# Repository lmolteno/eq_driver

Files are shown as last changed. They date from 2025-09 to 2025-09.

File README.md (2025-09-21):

# EQ Driver
## EQ3
Gear ratios:
RA seems to be about 5.46875:1 from the stepper to the worm, then the worm is about 130:1 (according to what I've read).

RA Stepper:
Big Gear: 66 teeth
interfaces with Stepper motor: 12 teeth

Big gear is attached to 35 teeth gear.
This is attached to another 35 tooth gear.
Total ratio is 66:12

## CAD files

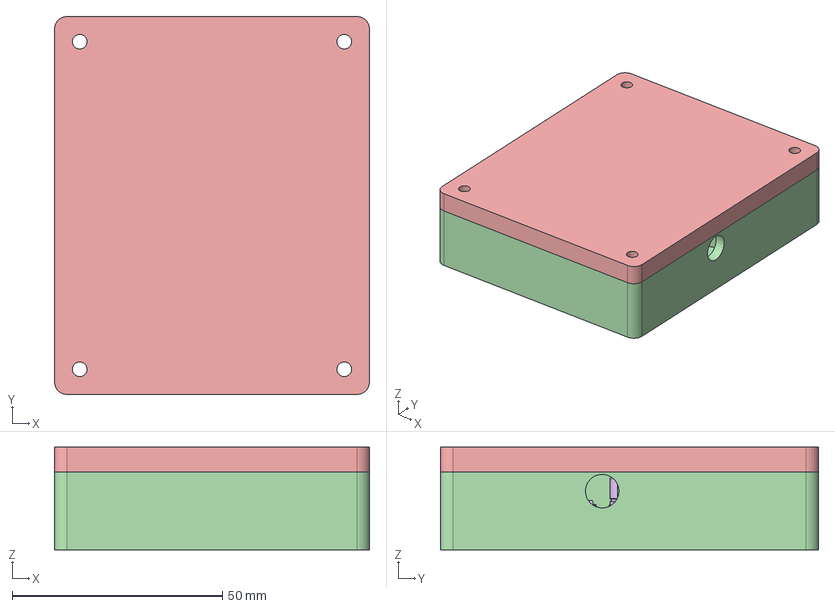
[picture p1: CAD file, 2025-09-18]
eq3_driver.FCStd
75.0 x 90.0 x 24.5 mm
Pcb_4df3
C34_C_0402_1005Metric_825b499ae89d x 18
R11_R_1206_3216Metric_94f444638870 x 4
SW-SMD_L3.9-W2.9-H2.0-LS4.8 x 3
SW-SMD_L3.9-W2.9-H2.0-LS4.009 x 3
SW-SMD_L3.9-W2.9-H2.0-LS4.010 x 3
SW-SMD_L3.9-W2.9-H2.0-LS4.011 x 3
SW-SMD_L3.9-W2.9-H2.0-LS4.012 x 3
SW-SMD_L3.9-W2.9-H2.0-LS4.013 x 3
SW-SMD_L3.9-W2.9-H2.0-LS4.014 x 3
SW-SMD_L3.9-W2.9-H2.0-LS4.015 x 3
SW-SMD_L3.9-W2.9-H2.0-LS4.016 x 3
SW-SMD_L3.9-W2.9-H2.0-LS4.017 x 3
SW-SMD_L3.9-W2.9-H2.0-LS4.018 x 3
SW-SMD_L3.9-W2.9-H2.0-LS4.019 x 3
SW-SMD_L3.9-W2.9-H2.0-LS4.020 x 3
SW-SMD_L3.9-W2.9-H2.0-LS4.021 x 3
SW-SMD_L3.9-W2.9-H2.0-LS4.022 x 3
SW-SMD_L3.9-W2.9-H2.0-LS4.023 x 3
J3_USB-C-TH_SHOUHAN_TYPE-C-14PLC-H10.0_6f067ef49c33 x 2
C30_C_0603_1608Metric_b4d60a828703 x 5
C_Elec_63x77 x 4
C_Elec_63x078 x 4
R5_R_0402_1005Metric_0c219b5e5636 x 7
J4_JST_B5B_PH_K_12af6bce2525[2] x 2
ESP32-S3-WROOM-1
ESP32-S3-WROOM-002
ESP32-S3-WROOM-003
ESP32-S3-WROOM-004
ESP32-S3-WROOM-005
ESP32-S3-WROOM-006
ESP32-S3-WROOM-007
ESP32-S3-WROOM-008
ESP32-S3-WROOM-009
ESP32-S3-WROOM-010
ESP32-S3-WROOM-011
ESP32-S3-WROOM-012
ESP32-S3-WROOM-013
ESP32-S3-WROOM-014
ESP32-S3-WROOM-015
ESP32-S3-WROOM-016
ESP32-S3-WROOM-017
ESP32-S3-WROOM-018
ESP32-S3-WROOM-019
ESP32-S3-WROOM-020
ESP32-S3-WROOM-021
ESP32-S3-WROOM-022
ESP32-S3-WROOM-023
ESP32-S3-WROOM-024
ESP32-S3-WROOM-025
ESP32-S3-WROOM-026
ESP32-S3-WROOM-027
ESP32-S3-WROOM-028
ESP32-S3-WROOM-029
ESP32-S3-WROOM-030
ESP32-S3-WROOM-031
ESP32-S3-WROOM-032
ESP32-S3-WROOM-033
ESP32-S3-WROOM-034
ESP32-S3-WROOM-035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

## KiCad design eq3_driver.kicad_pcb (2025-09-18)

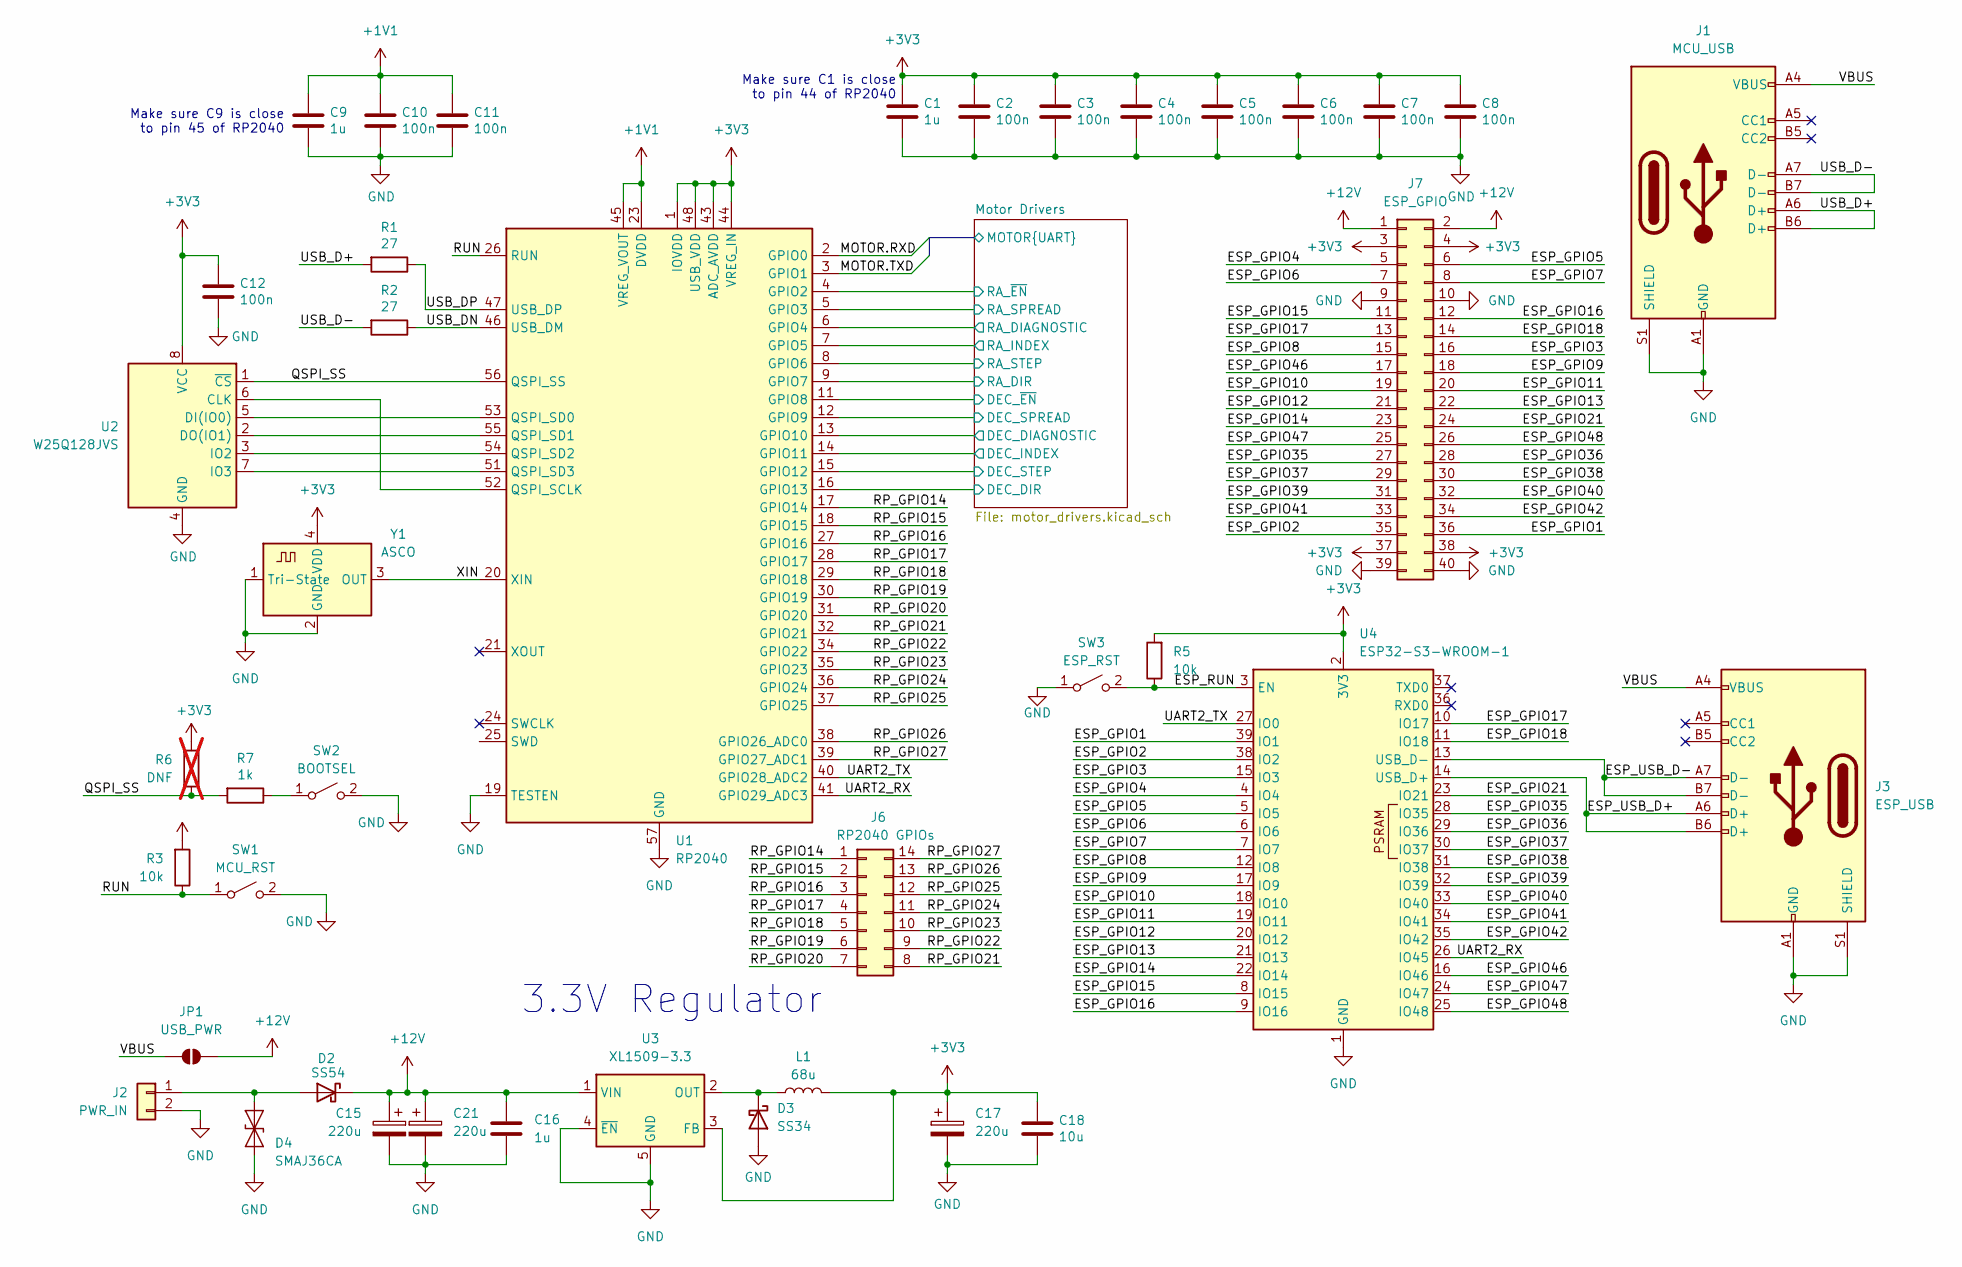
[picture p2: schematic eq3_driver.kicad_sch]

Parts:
C1, C9: 1u; C_0402_1005Metric; LCSC C52923
C2, C3, C4, C5, C6, C7, C8, C10, C11, C12: 100n; C_0402_1005Metric; LCSC C1525
C15, C21: 220u; C_Elec_6.3x7.7; LCSC C5246541
C16: 1u; C_0603_1608Metric; LCSC C15849
C17: 220u; CP_EIA-3528-21_Kemet-B; LCSC C30242
C18: 10u; C_0805_2012Metric; LCSC C15850
D2: SS54; D_SMA; LCSC C22452
D3: SS34; D_SMA; LCSC C8678
D4: SMAJ36CA; D_SMA; LCSC C87270
J1: MCU_USB; USB-C-TH_SHOUHAN_TYPE-C-14PLC-H10.0; LCSC C3151746
J2: PWR_IN; SolderWire-1sqmm_1x02_P5.4mm_D1.4mm_OD2.7mm
J3: ESP_USB; USB-C-TH_SHOUHAN_TYPE-C-14PLC-H10.0; LCSC C3151746
J6: RP2040 GPIOs; PinHeader_2x07_P2.00mm_Vertical
J7: ESP_GPIO; PinHeader_2x20_P2.00mm_Vertical
JP1: USB_PWR; SolderJumper-2_P1.3mm_Open_TrianglePad1.0x1.5mm
L1: 68u; L_Wuerth_WE-PD2-Typ-MS; LCSC C2929435
R1, R2: 27; R_0402_1005Metric; LCSC C25100
R3, R5: 10k; R_0402_1005Metric; LCSC C25744
R6: DNF; R_0402_1005Metric; LCSC C25744; not fitted
R7: 1k; R_0402_1005Metric; LCSC C11702
SW1: MCU_RST; SW-SMD_L3.9-W3.0-P4.45; LCSC C720477
SW2: BOOTSEL; SW-SMD_L3.9-W3.0-P4.45; LCSC C720477
SW3: ESP_RST; SW-SMD_L3.9-W3.0-P4.45; LCSC C720477
U1: RP2040; QFN-56-1EP_7x7mm_P0.4mm_EP3.2x3.2mm; LCSC C2040
U2: W25Q128JVS; SOIC-8_5.3x5.3mm_P1.27mm; LCSC C97521
U3: XL1509-3.3; SO-8_3.9x4.9mm_P1.27mm; LCSC C74193
U4: ESP32-S3-WROOM-1
Y1: ASCO; Crystal_SMD_5032-4Pin_5.0x3.2mm; LCSC C19674262

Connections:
+1V1: C9.1, C10.1, C11.1, U1.23 (DVDD), U1.45 (VREG_VOUT), U1.50 (DVDD)
+3V3: C1.1, C2.1, C3.1, C4.1, C5.1, C6.1, C7.1, C8.1, C12.1, C17.1, C18.1, J7.3, J7.4, J7.37, J7.38, L1.2, R3.2, R5.2, R6.2, U1.1 (IOVDD), U1.10 (IOVDD), U1.22 (IOVDD), U1.33 (IOVDD), U1.42 (IOVDD), U1.43 (ADC_AVDD), U1.44 (VREG_IN), U1.48 (USB_VDD), U1.49 (IOVDD), U2.8 (VCC), U3.3 (FB), U4.2 (3V3), Y1.4 (VDD); also elsewhere on the board
+12V: C15.1, C16.1, C21.1, D2.1 (K), J7.1, J7.2, JP1.2 (B), U3.1 (VIN); also elsewhere on the board
/ESP_GPIO1: J7.36, U4.39 (IO1)
/ESP_GPIO2: J7.35, U4.38 (IO2)
/ESP_GPIO3: J7.16, U4.15 (IO3)
/ESP_GPIO4: J7.5, U4.4 (IO4)
/ESP_GPIO5: J7.6, U4.5 (IO5)
/ESP_GPIO6: J7.7, U4.6 (IO6)
/ESP_GPIO7: J7.8, U4.7 (IO7)
/ESP_GPIO8: J7.15, U4.12 (IO8)
/ESP_GPIO9: J7.18, U4.17 (IO9)
/ESP_GPIO10: J7.19, U4.18 (IO10)
/ESP_GPIO11: J7.20, U4.19 (IO11)
/ESP_GPIO12: J7.21, U4.20 (IO12)
/ESP_GPIO13: J7.22, U4.21 (IO13)
/ESP_GPIO14: J7.23, U4.22 (IO14)
/ESP_GPIO15: J7.11, U4.8 (IO15)
/ESP_GPIO16: J7.12, U4.9 (IO16)
/ESP_GPIO17: J7.13, U4.10 (IO17)
/ESP_GPIO18: J7.14, U4.11 (IO18)
/ESP_GPIO21: J7.24, U4.23 (IO21)
/ESP_GPIO35: J7.27, U4.28 (IO35)
/ESP_GPIO36: J7.28, U4.29 (IO36)
/ESP_GPIO37: J7.29, U4.30 (IO37)
/ESP_GPIO38: J7.30, U4.31 (IO38)
/ESP_GPIO39: J7.31, U4.32 (IO39)
/ESP_GPIO40: J7.32, U4.33 (IO40)
/ESP_GPIO41: J7.33, U4.34 (IO41)
/ESP_GPIO42: J7.34, U4.35 (IO42)
/ESP_GPIO46: J7.17, U4.16 (IO46)
/ESP_GPIO47: J7.25, U4.24 (IO47)
/ESP_GPIO48: J7.26, U4.25 (IO48)
/ESP_RUN: R5.1, SW3.2 (B), U4.3 (EN)
/ESP_USB_D+: J3.A6 (D+), J3.B6 (D+), U4.14 (USB_D+)
/ESP_USB_D-: J3.A7 (D-), J3.B7 (D-), U4.13 (USB_D-)
/Motor Drivers/DEC_DIAGNOSTIC: U1.13 (GPIO10); also elsewhere on the board
/Motor Drivers/DEC_DIR: U1.16 (GPIO13); also elsewhere on the board
/Motor Drivers/DEC_INDEX: U1.14 (GPIO11); also elsewhere on the board
/Motor Drivers/DEC_SPREAD: U1.12 (GPIO9); also elsewhere on the board
/Motor Drivers/DEC_STEP: U1.15 (GPIO12); also elsewhere on the board
/Motor Drivers/DEC_~EN: U1.11 (GPIO8); also elsewhere on the board
/Motor Drivers/MOTOR.RXD: U1.2 (GPIO0); also elsewhere on the board
/Motor Drivers/MOTOR.TXD: U1.3 (GPIO1); also elsewhere on the board
/Motor Drivers/RA_DIAGNOSTIC: U1.6 (GPIO4); also elsewhere on the board
/Motor Drivers/RA_DIR: U1.9 (GPIO7); also elsewhere on the board
/Motor Drivers/RA_INDEX: U1.7 (GPIO5); also elsewhere on the board
/Motor Drivers/RA_SPREAD: U1.5 (GPIO3); also elsewhere on the board
/Motor Drivers/RA_STEP: U1.8 (GPIO6); also elsewhere on the board
/Motor Drivers/RA_~EN: U1.4 (GPIO2); also elsewhere on the board
/QSPI_SS: R6.1, R7.2, U1.56 (QSPI_SS), U2.1 (~CS)
/RP_GPIO14: J6.1, U1.17 (GPIO14)
/RP_GPIO15: J6.2, U1.18 (GPIO15)
/RP_GPIO16: J6.3, U1.27 (GPIO16)
/RP_GPIO17: J6.4, U1.28 (GPIO17)
/RP_GPIO18: J6.5, U1.29 (GPIO18)
/RP_GPIO19: J6.6, U1.30 (GPIO19)
/RP_GPIO20: J6.7, U1.31 (GPIO20)
/RP_GPIO21: J6.8, U1.32 (GPIO21)
/RP_GPIO22: J6.9, U1.34 (GPIO22)
/RP_GPIO23: J6.10, U1.35 (GPIO23)
/RP_GPIO24: J6.11, U1.36 (GPIO24)
/RP_GPIO25: J6.12, U1.37 (GPIO25)
/RP_GPIO26: J6.13, U1.38 (GPIO26_ADC0)
/RP_GPIO27: J6.14, U1.39 (GPIO27_ADC1)
/RUN: R3.1, SW1.1 (A), U1.26 (RUN)
/UART2_RX: U1.41 (GPIO29_ADC3), U4.26 (IO45)
/UART2_TX: U1.40 (GPIO28_ADC2), U4.27 (IO0)
/USB_D+: J1.A6 (D+), J1.B6 (D+), R1.2
/USB_D-: J1.A7 (D-), J1.B7 (D-), R2.2
/USB_DN: R2.1, U1.46 (USB_DM)
/USB_DP: R1.1, U1.47 (USB_DP)
/VBUS: J1.A4 (VBUS), J1.A9 (VBUS), J1.B4 (VBUS), J1.B9 (VBUS), J3.A4 (VBUS), J3.A9 (VBUS), J3.B4 (VBUS), J3.B9 (VBUS), JP1.1 (A)
/XIN: U1.20 (XIN), Y1.3 (OUT)
GND: C1.2, C2.2, C3.2, C4.2, C5.2, C6.2, C7.2, C8.2, C9.2, C10.2, C11.2, C12.2, C15.2, C16.2, C17.2, C18.2, C21.2, D3.2 (A), D4.1 (A1), J1.A1 (GND), J1.A12 (GND), J1.B1 (GND), J1.B12 (GND), J1.S1 (SHIELD), J2.2, J3.A1 (GND), J3.A12 (GND), J3.B1 (GND), J3.B12 (GND), J3.S1 (SHIELD), J7.9, J7.10, J7.39, J7.40, SW1.2 (B), SW2.2 (B), SW3.1 (A), U1.19 (TESTEN), U1.57 (GND), U2.4 (GND), U3.4 (~EN), U3.5 (GND), U3.6 (GND), U3.7 (GND), U3.8 (GND), U4.1 (GND), U4.40 (GND), U4.41 (GND), Y1.1 (Tri-State), Y1.2 (GND); also elsewhere on the board
unnamed: D2.2 (A), D4.2 (A2), J2.1
unnamed: D3.1 (K), L1.1, U3.2 (OUT)
unnamed: R7.1, SW2.1 (A)
unnamed: U1.52 (QSPI_SCLK), U2.6 (CLK)
unnamed: U1.53 (QSPI_SD0), U2.5 (DI(IO0))
unnamed: U1.55 (QSPI_SD1), U2.2 (DO(IO1))
unnamed: U1.54 (QSPI_SD2), U2.3 (IO2)
unnamed: U1.51 (QSPI_SD3), U2.7 (IO3)

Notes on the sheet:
Make sure C9 is close to pin 45 of RP2040
Make sure C1 is close to pin 44 of RP2040
3.3V Regulator

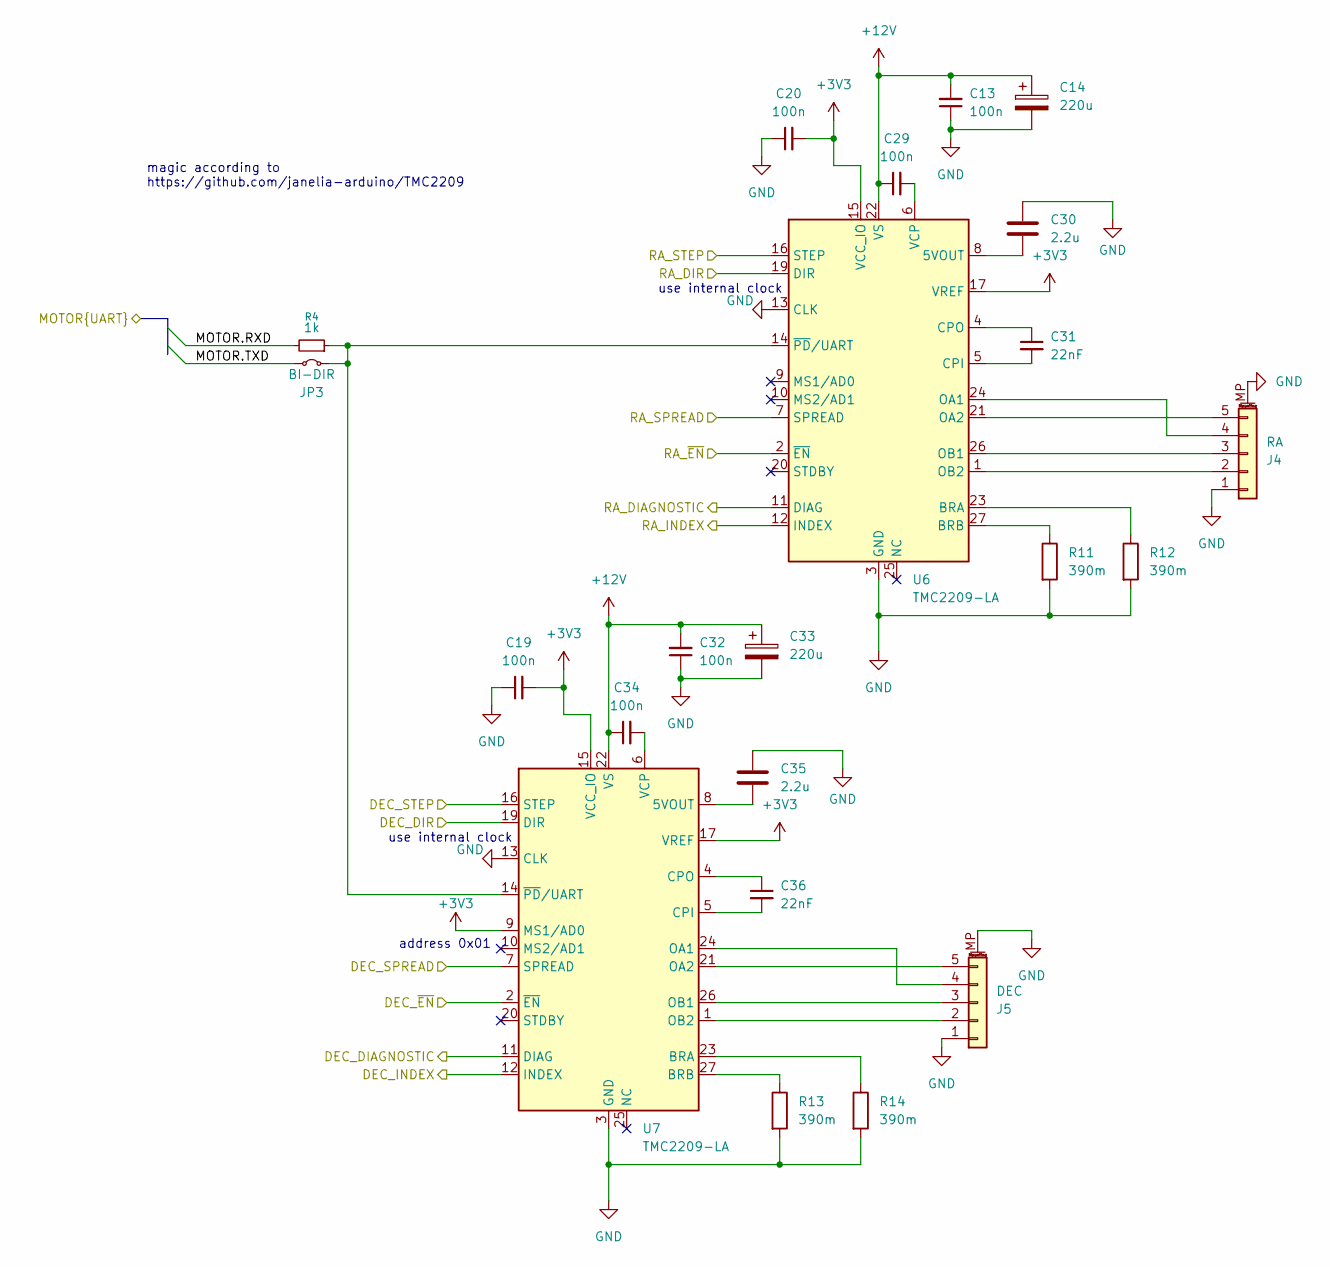
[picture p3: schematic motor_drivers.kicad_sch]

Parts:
C13, C19, C20, C29, C32, C34: 100n; C_0402_1005Metric; LCSC C1525
C14, C33: 220u; C_Elec_6.3x7.7; LCSC C5246541
C30, C35: 2.2u; C_0603_1608Metric; LCSC C23630
C31, C36: 22nF; C_0603_1608Metric; LCSC C21122
J4: RA; JST_PH_B5B-PH-SM4-TB_1x05-1MP_P2.00mm_Vertical; LCSC C265085
J5: DEC; JST_PH_B5B-PH-SM4-TB_1x05-1MP_P2.00mm_Vertical; LCSC C265085
JP3: BI-DIR; SolderJumper-2_P1.3mm_Bridged_RoundedPad1.0x1.5mm
R4: 1k; R_0402_1005Metric; LCSC C11702
R11, R12, R13, R14: 390m; R_1206_3216Metric; LCSC C188072
U6, U7: TMC2209-LA; VQFN-28-1EP_5x5mm_P0.5mm_EP3.7x3.7mm; LCSC C2150710

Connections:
+3V3: C19.2, C20.2, U6.15 (VCC_IO), U6.17 (VREF), U7.9 (MS1/AD0), U7.15 (VCC_IO), U7.17 (VREF); also elsewhere on the board
+12V: C13.2, C14.1, C29.1, C32.2, C33.1, C34.1, U6.22 (VS), U6.28 (VS), U7.22 (VS), U7.28 (VS); also elsewhere on the board
/Motor Drivers/DEC_DIAGNOSTIC: U7.11 (DIAG); also elsewhere on the board
/Motor Drivers/DEC_DIR: U7.19 (DIR); also elsewhere on the board
/Motor Drivers/DEC_INDEX: U7.12 (INDEX); also elsewhere on the board
/Motor Drivers/DEC_SPREAD: U7.7 (SPREAD); also elsewhere on the board
/Motor Drivers/DEC_STEP: U7.16 (STEP); also elsewhere on the board
/Motor Drivers/DEC_~EN: U7.2 (~EN); also elsewhere on the board
/Motor Drivers/MOTOR.RXD: R4.2; also elsewhere on the board
/Motor Drivers/MOTOR.TXD: JP3.2 (B); also elsewhere on the board
/Motor Drivers/RA_DIAGNOSTIC: U6.11 (DIAG); also elsewhere on the board
/Motor Drivers/RA_DIR: U6.19 (DIR); also elsewhere on the board
/Motor Drivers/RA_INDEX: U6.12 (INDEX); also elsewhere on the board
/Motor Drivers/RA_SPREAD: U6.7 (SPREAD); also elsewhere on the board
/Motor Drivers/RA_STEP: U6.16 (STEP); also elsewhere on the board
/Motor Drivers/RA_~EN: U6.2 (~EN); also elsewhere on the board
GND: C13.1, C14.2, C19.1, C20.1, C30.1, C32.1, C33.2, C35.1, J4.1, J4.MP (MountPin), J5.1, J5.MP (MountPin), R11.2, R12.2, R13.2, R14.2, U6.3 (GND), U6.13 (CLK), U6.18 (GND), U6.29 (GND), U7.3 (GND), U7.13 (CLK), U7.18 (GND), U7.29 (GND); also elsewhere on the board
unnamed: J4.2, U6.1 (OB2)
unnamed: J4.3, U6.26 (OB1)
unnamed: J4.4, U6.24 (OA1)
unnamed: J4.5, U6.21 (OA2)
unnamed: J5.2, U7.1 (OB2)
unnamed: J5.3, U7.26 (OB1)
unnamed: J5.4, U7.24 (OA1)
unnamed: J5.5, U7.21 (OA2)
unnamed: JP3.1 (A), R4.1, U6.14 (~PD/UART), U7.14 (~PD/UART)
unnamed: C30.2, U6.8 (5VOUT)
unnamed: R12.1, U6.23 (BRA)
unnamed: R11.1, U6.27 (BRB)
unnamed: C31.2, U6.5 (CPI)
unnamed: C31.1, U6.4 (CPO)
unnamed: C29.2, U6.6 (VCP)
unnamed: C35.2, U7.8 (5VOUT)
unnamed: R14.1, U7.23 (BRA)
unnamed: R13.1, U7.27 (BRB)
unnamed: C36.2, U7.5 (CPI)
unnamed: C36.1, U7.4 (CPO)
unnamed: C34.2, U7.6 (VCP)

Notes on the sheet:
address 0x01
magic according to https://github.com/janelia-arduino/TMC2209
use internal clock

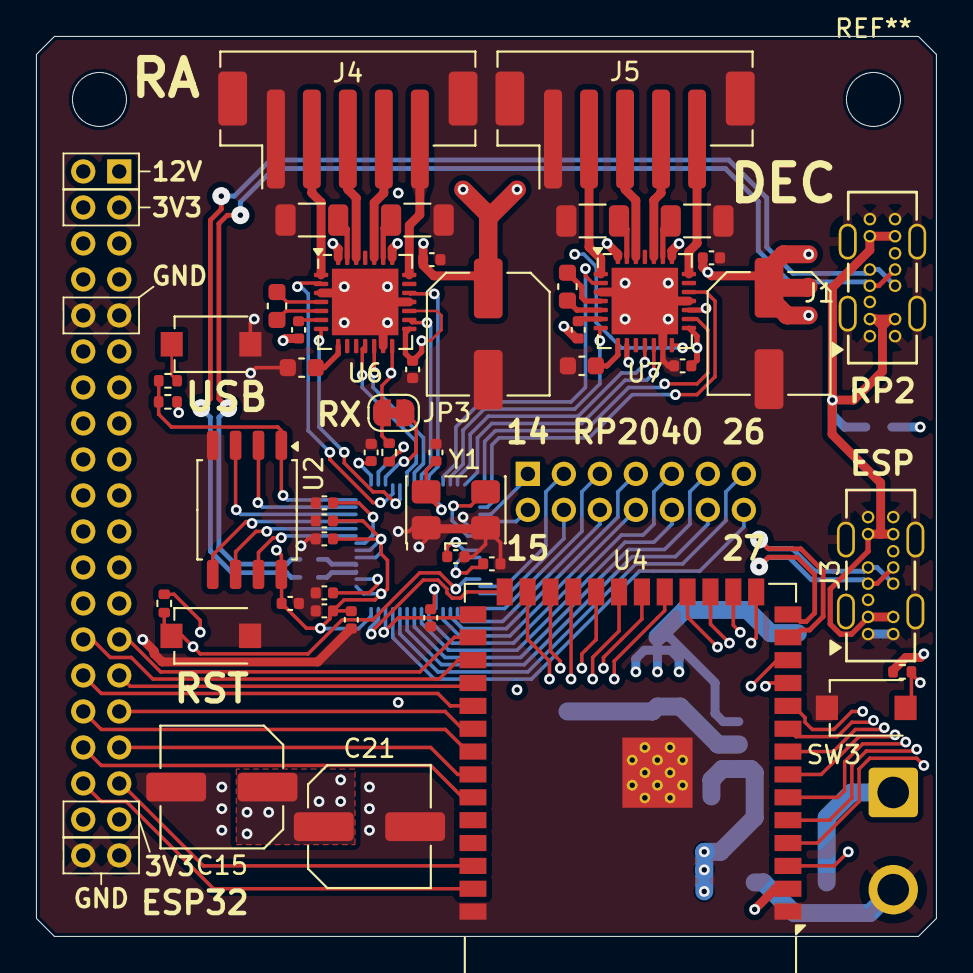
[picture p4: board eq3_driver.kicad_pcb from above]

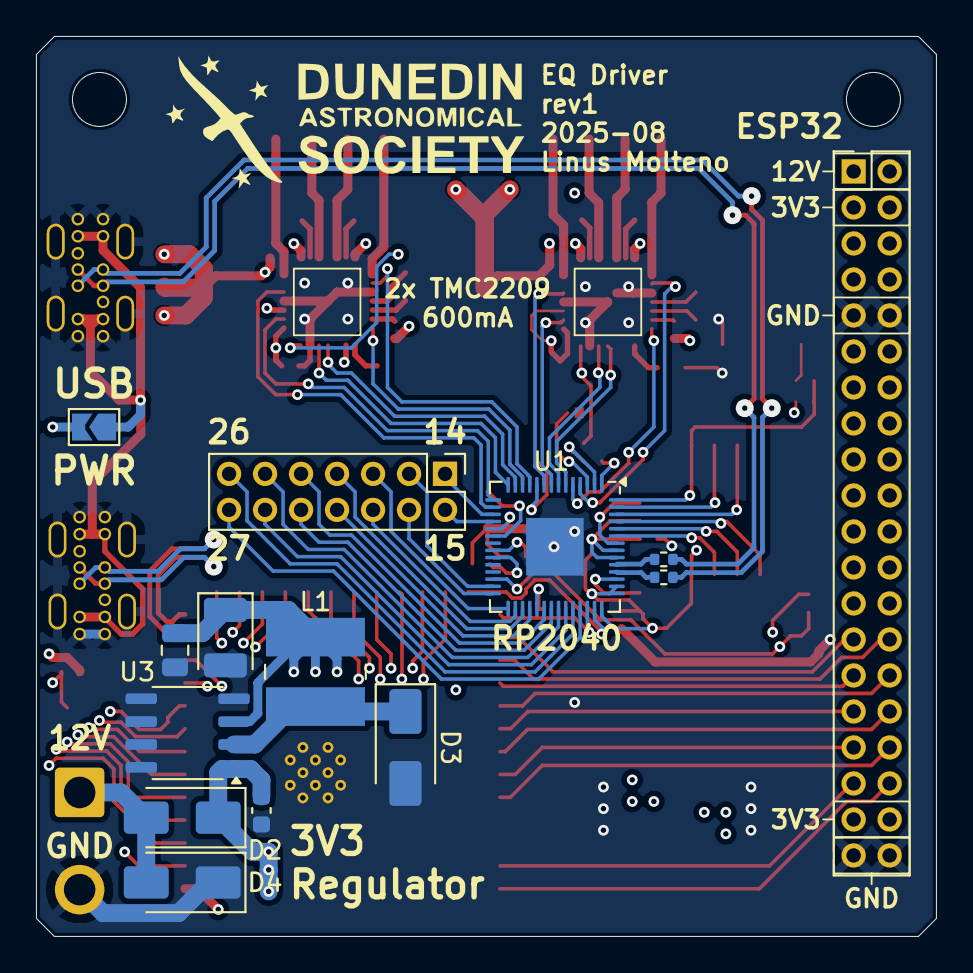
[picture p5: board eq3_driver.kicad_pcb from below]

Board: 4 copper layers, 50.0 x 50.0 mm, 63 parts (15 on the bottom side), 104 nets.

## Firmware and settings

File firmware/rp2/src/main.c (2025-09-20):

#include <stdio.h>
#include "pico/stdlib.h"
#include "pico/time.h"
#include "hardware/clocks.h"
#include "hardware/gpio.h"
#include "motor_control.h"
#include "telescope_protocol.h"

// Global system state
static motor_system_t motor_system;

int main() {
    // Initialize standard I/O
    stdio_init_all();
    
    printf("\\n=== RP2040 Telescope Mount Controller ===\\n");
    printf("Initializing system...\\n");
    
    // Get system clock frequency
    uint32_t sys_clock = clock_get_hz(clk_sys);
    printf("System clock: %u Hz\\n", (unsigned int)sys_clock);
    
    // Add delay for system stability
    sleep_ms(100);
    
    // Initialize motor control system
    int motor_init_result = motor_system_init(&motor_system, sys_clock);
    if (motor_init_result != 0) {
        printf("ERROR: Failed to initialize motor system! Code: %d\\n", motor_init_result);
        while (1) {
            sleep_ms(1000);
            printf("Motor system init failed - halted\\n");
        }
    }
    
    // Initialize communication protocol
    if (protocol_init() != 0) {
        printf("ERROR: Failed to initialize protocol system!\\n");
        while (1) {
            sleep_ms(1000);
            printf("Protocol init failed - halted\\n");
        }
    }

    sleep_ms(1000);


    // Link motor system to protocol handler
    protocol_set_motor_system(&motor_system);
    
    printf("System initialized successfully!\n");
    printf("Waiting for ESP32 commands...\n");
    
    // Main control loop
    absolute_time_t last_update = get_absolute_time();
    // const uint32_t UPDATE_INTERVAL_US = 10000;  // 100Hz update rate
    bool updated_pvt = false;
    
    while (1) {
        // Process protocol messages and send status reports
        protocol_task();
        
        // Update motor control system at regular intervals
        motor_update_task(&motor_system);

        // Small delay to prevent busy-waiting
        sleep_us(1000);
        // tight_loop_contents();
    }
    
    return 0;
}

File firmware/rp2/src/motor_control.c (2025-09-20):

#include <stdio.h>
#include <string.h>
#include <math.h>
#include <stdlib.h>
#include "pico/stdlib.h"
#include "pico/time.h"
#include "hardware/uart.h"
#include "hardware/pio.h"
#include "hardware/gpio.h"
#include "hardware/clocks.h"
#include "hardware/irq.h"
#include "motor_control.h"
#include "tmc2209.h"
#include "step_generator.pio.h"

#define INTEGRAL_MAX 100000
#define INTEGRAL_MIN (-100000)
#define MAX_ACCELERATION 8000 // steps per second per second
#define STARTUP_VELOCITY 500
#define MAX_VELOCITY 15000

// Global motor system state
static motor_system_t *g_motor_system = NULL;

// PIO state
static PIO step_pio = pio0;
static uint step_program_offset;

// TMC2209 UART
uart_inst_t *motor_uart = uart0;

// Position tracking and FIFO management
static volatile int32_t step_counts[NUM_AXES] = {0, 0};
static volatile uint16_t current_step_delay[NUM_AXES] = {0xFFFF, 0xFFFF}; // Current delay for each axis
static volatile bool current_direction[NUM_AXES] = {true, true}; // Current direction for each axis
static volatile double previous_error[NUM_AXES] = {0, 0};
static volatile double_t error_integral[NUM_AXES] = {0, 0};
static volatile uint64_t previous_update_time[NUM_AXES] = {0, 0};

// Internal function prototypes
static void configure_tmc2209(motor_system_t *sys, uint8_t axis);

static void feed_step_fifo(motor_system_t *sys, uint8_t axis);

static void pio_step_irq_handler(void);

static uint16_t velocity_to_step_delay(float velocity_steps_per_sec, float pio_freq);

/**
 * Initialize the motor control system
 */
int motor_system_init(motor_system_t *sys, uint32_t clock_hz) {
    if (!sys) return -1;

    memset(sys, 0, sizeof(motor_system_t));
    sys->system_clock_hz = clock_hz;
    sys->tmc_uart = motor_uart;

    // Store global reference
    g_motor_system = sys;

    // Initialize TMC2209 UART
    tmc2209_config_t tmc_config = {
        .uart = motor_uart,
        .tx_pin = 0,
        .rx_pin = 1,
        .baudrate = 115200
    };

    printf("Initializing TMC2209 UART...\n");
    int tmc_result = tmc2209_init(&tmc_config);
    if (tmc_result != 0) {
        printf("Failed to initialize TMC2209 UART, code: %d\n", tmc_result);
        return -1;
    }
    printf("TMC2209 UART initialized successfully\n");

    // Load PIO program once
    step_program_offset = pio_add_program(step_pio, &step_generator_program);

    // Initialize step generators for both axes using same PIO, different state machines
    // RA axis: Step=GP6, Dir=GP7, PIO0 SM0
    sys->axes[AXIS_RA].step_gen.sm = 0;
    setup_step_generator(&sys->axes[AXIS_RA].step_gen, step_pio, 6, 7, clock_hz, step_program_offset);

    // DEC axis: Step=GP12, Dir=GP13, PIO0 SM1
    sys->axes[AXIS_DEC].step_gen.sm = 1;
    setup_step_generator(&sys->axes[AXIS_DEC].step_gen, step_pio, 12, 13, clock_hz, step_program_offset);

    // Configure TMC2209 drivers
    configure_tmc2209(sys, AXIS_RA);
    configure_tmc2209(sys, AXIS_DEC);

    for (int i = 0; i < NUM_AXES; i++) {
        sys->axes[i].p_gain = 2000;
        sys->axes[i].i_gain = 500;
        sys->axes[i].d_gain = 800;
        sys->axes[i].velocity = 0;
    }

    printf("Motor system initialized with %d axes\n", NUM_AXES);
    return 0;
}

/**
 * Set up a step generator PIO state machine
 */
void setup_step_generator(step_generator_t *gen, PIO pio, uint step_pin, uint dir_pin, float sys_clock,
                          uint program_offset) {
    gen->pio = pio;
    gen->step_pin = step_pin;
    gen->dir_pin = dir_pin;
    gen->offset = program_offset;

    // Configure step pin for PIO control
    pio_gpio_init(pio, step_pin);

    // Configure direction pin for regular GPIO control
    gpio_init(dir_pin);
    gpio_set_dir(dir_pin, GPIO_OUT);
    gpio_put(dir_pin, false); // Default direction

    // Configure state machine
    pio_sm_config c = step_generator_program_get_default_config(gen->offset);

    // Set pins: SET for step pulse output
    sm_config_set_set_pins(&c, step_pin, 1);

    // Set GPIO direction for step pin
    pio_sm_set_consecutive_pindirs(pio, gen->sm, step_pin, 1, true);

    // Set clock divider for precise timing (target ~10MHz for 100ns resolution)
    float target_freq = 10000000.0f; // 10MHz
    gen->clock_div = sys_clock / target_freq;
    if (gen->clock_div < 1.0f) gen->clock_div = 1.0f;
    sm_config_set_clkdiv(&c, gen->clock_div);

    // Initialize and start state machine
    pio_sm_init(pio, gen->sm, gen->offset, &c);
    pio_sm_set_enabled(pio, gen->sm, true);

    printf("PIO%d SM%d: step_pin=%d, dir_pin=%d, clock_div=%.2f\\n",
           pio_get_index(pio), gen->sm, step_pin, dir_pin, gen->clock_div);
}

/**
 * Configure TMC2209 driver for telescope application
 */
static void configure_tmc2209(motor_system_t *sys, uint8_t axis) {
    if (axis >= NUM_AXES) return;

    // Configure GCONF register
    uint32_t gconf = 0x000001C0; // Enable UART, set PDN_UART, set MSTEP_REG_SELECT
    tmc2209_write_register(sys->tmc_uart, axis, 0x00, gconf);

    // Configure CHOPCONF for smooth operation
    uint32_t chopconf = generate_chopconf(
        0, // diss2vs
        0, // diss2g
        0, // dedge
        1, // intpol (enable interpolation)
        4, // mres (16 microsteps)
        0, // vsense
        2, // tbl
        0, // hend
        5, // hstrt
        3 // toff
    );
    tmc2209_write_register(sys->tmc_uart, axis, 0x6C, chopconf);

    // Set current levels (adjust for your motors)
    uint32_t ihold_irun_val = ihold_irun(
        8, // ihold (hold current)
        16, // irun (run current)
        10 // iholddelay
    );
    tmc2209_write_register(sys->tmc_uart, axis, 0x10, ihold_irun_val);

    printf("TMC2209 axis %d configured\n", axis);
}

/**
 * Set velocity for an axis
 */
void motor_set_velocity(motor_system_t *sys, uint8_t axis, float velocity) {
    if (!sys || axis >= NUM_AXES) return;

    motor_axis_t *ax = &sys->axes[axis];
    ax->velocity = velocity;
    ax->direction = (velocity >= 0);

    // Update PIO step generator
    update_step_rate(&ax->step_gen, velocity, sys->system_clock_hz);
}

/**
 * Set target position for goto move
 */
void motor_set_position(motor_system_t *sys, uint8_t axis, int32_t target, uint16_t max_speed) {
    if (!sys || axis >= NUM_AXES) return;

    motor_axis_t *ax = &sys->axes[axis];
    ax->max_speed = max_speed;

    // For now, implement simple move - could add acceleration profiles later
    int32_t position_diff = target - ax->position;
    if (position_diff != 0) {
        float move_velocity = (position_diff > 0) ? max_speed : -max_speed;
        motor_set_velocity(sys, axis, move_velocity);
        printf("Axis %d goto: current=%d, target=%d, velocity=%d\n",
               axis, (int) ax->position, (int) target, move_velocity);
    }
}
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

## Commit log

2025-09-18 feat: hardware
    [eq3_driver.FCStd, eq3_driver.kicad_pcb, eq3_driver.kicad_sch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]
2025-09-18 feat: rp2040 firmware (pid control)
2025-09-20 feat: it works - just tweaking to float velocities.
    [telescope_mount.cfg]
2025-09-20 feat: full workflow going - established gear ratios
